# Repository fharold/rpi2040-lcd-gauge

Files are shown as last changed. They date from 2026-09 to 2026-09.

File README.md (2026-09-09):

# universal_gauges

Basic and versatile gauges based on the WAVESHARE RP2040-LCD-1.28 module.
A small HAT enhances it:

- 2 analog sensor inputs (divider stuffed to suit the sender, 5 V supply)
- 2 digital inputs (level shifted)
- 1 ambient light sensor
- 1 button
- 2 relay outputs

The firmware sources are in the repository root; the HAT itself is a KiCad
project in `pcb/`, described in [The HAT board](#the-hat-board).

The target is the **RP2040-LCD-1.28**. The touch variant is not supported: its
user button sits on GP16, which the HAT uses for its first digital input, so
the two would share one pin.

## Pinout

Signals added by the HAT:

| GPIO | Signal | Direction |
| ---- | --- | --- |
| GP16 | shifted_digital_in1 | input |
| GP17 | shifted_digital_in2 | input |
| GP18 | button_input | input, pull-up |
| GP19 | relay1_command_pin | output |
| GP20 | relay2_command_pin | output |
| GP26 | als_out | analog input, ADC0 |
| GP27 | sensor2_filtered | analog input, ADC1 |
| GP28 | sensor1_filtered | analog input, ADC2 |

The RP2040 ADC channel is not the GPIO number: GP26 is ADC0, GP27 is ADC1,
GP28 is ADC2, and GP29 (ADC3) is the module's own battery sense.

Pins used by the module itself (display, I2C, IMU, backlight, battery) are
defined in `lib/lcd/lcd.h`.

## The HAT board

The HAT is a KiCad 10 project, `pcb/rpi2040-lcd-gauge.kicad_pro`: a two-layer
board, 1.6 mm, 35 x 38.7 mm, whose lower edge is a semicircle following the
module. It sits
behind the RP2040-LCD-1.28 and connects to it through J2, a 2x10 1.27 mm
header. J1 is the header on the other side of the module; it is mechanical
only, none of its pads is connected.

The schematic is hierarchical, one sheet per function:

| Sheet | File | Contents |
| ----- | ---- | --- |
| psu | `PSU.kicad_sch` | input protection, 12 V -> 5 V buck |
| ain_1, ain_2 | `sensor_1.kicad_sch`, `sensor_2.kicad_sch` | analog input dividers |
| din_1, din_2 | `digital_in_1.kicad_sch`, `digital_in_2.kicad_sch` | level-shifted digital inputs |
| relay_1, relay_2 | `output_relay_1.kicad_sch`, `relay.kicad_sch` | low-side relay drivers |
| als | `als.kicad_sch` | ambient light sensor |
| switch | `switch.kicad_sch` | push button |

### Connectors

All field wiring is on JST XH connectors, 2.5 mm pitch.

| Ref | Type | Pin 1 | Pin 2 | Pin 3 | Pin 4 |
| --- | ---- | ----- | ----- | ----- | ----- |
| J5 | XH 4 | GND | digital_in1 | digital_in2 | +12 V in |
| J7 | XH 3 | sensor1 signal | GND | +5 V out | |
| J8 | XH 3 | sensor2 signal | GND | +5 V out | |
| J3 | XH 2 | +12 V | relay1 coil, low-side switched | | |
| J4 | XH 2 | +12 V | relay2 coil, low-side switched | | |

J2 carries GP16-GP22 to the module, +5 V to it, 3.3 V back from it, and GND.

### Power

The 12 V input passes through F1 (1 A), Q1 (P-channel MOSFET, reverse polarity
protection) and D2 (SMBJ36A TVS) onto the protected +12 V rail, which also
feeds the relay connectors. U1, an LMR16006 buck with L1 (22 uH) and the
R2/R3 feedback divider (54k9 / 10k), makes 5 V from that rail and supplies the
module through J2. The 3.3 V used by the ambient light sensor comes back from
the module's own regulator.

### Input and output stages

**Analog inputs.** Each is a divider to GND: R15 in series, the ADC pin, then
R16 to ground (R17/R18 on the second channel). **The two resistors are stuffed
to suit the sender the board is built for**, so a board and the firmware
variant flashed on it have to match.

*Pressure board, R15 = R16 = 100 k.* The sender has a voltage output and the
divider simply halves it: a 0.5-4.5 V sender spans 250-2250 mV at the pin.
Source impedance there is 50 k.

*Temperature board, R15 = 6 k, R16 = 10 k.* The sender is resistive and wired
between the connector's +5 V and its signal pin, so it becomes the top of the
divider and the pin reads

    V = 5 V x 10k / (R_sender + 16k)

which is 3.125 V with the sender shorted — comfortably under the 3.3 V full
scale — and 0 V with it open or its wire broken. Source impedance runs 4 to
7 k over the sender's range.

**Digital inputs.** Each is clamped by an SMAJ18A, divided 10 k / 100 k,
clamped again by a BZX84C12, and drives the gate of a BSS138 whose drain is
the GPIO, pulled up to 3.3 V through 10 k with 10 nF to GND. **The stage
inverts**: the GPIO reads low when the input is driven high, and idles high
when the input is open or grounded.

**Relay outputs.** GP19 and GP20 drive IRLML0060 MOSFETs through 1 k, with
100 k gate pulldowns, switching the low side of a coil fed from +12 V. There
is no flyback diode on the HAT: use a relay that has one built in, or fit one
across the coil.

**Button and light sensor.** SW1 pulls GP18 to GND, against the RP2040's
internal pull-up. U3, an SFH 5711 logarithmic light sensor, sinks its output
current into R11 (47 k) on GP26.

### Fabrication

`pcb/gerber/` holds the plot exported from KiCad 10.0.5, also zipped as
`pcb/gerber.zip`: two copper layers, mask, silkscreen, paste, and the PTH and
NPTH drill files. `pcb/rpi2040-lcd-gauge.csv` is the BOM.

## Source layout

| File | Contents |
| ---- | --- |
| `main.c` | bring-up order and the main loop, nothing else |
| `config.h` | every number you would tune: sensor spans, scales, backlight, sampling |
| `variant.h`, `variant.c` | the gauge variants, and the one this build selects |
| `board.h`, `board.c` | pin map, I2C scan, which of the two modules is running |
| `sensors.h`, `sensors.c` | ADC readings and their conversion to engineering units |
| `gauge.h`, `gauge.c` | frame buffer, gauge face and needle |
| `demo.h`, `demo.c` | the demo sweep, only compiled into a `USE_DEMO` build |
| `w.c`, `lib/` | widgets, drawing and display, from picoclock |

## Build variants

The firmware is built in three variants, selected at compile time by
`CURRENT_MODE`. One `cmake` + `make` builds all three:

| Variant | `CURRENT_MODE` | Gauge | Output |
| --- | --- | ----- | --- |
| engine oil temperature | `MODE_OIL_T` | 50-140 °C | `main_oil_t.uf2` |
| gearbox oil temperature | `MODE_GEARBOX_T` | 50-140 °C | `main_gearbox_t.uf2` |
| engine oil pressure | `MODE_OIL_P` | -0.5-6.5 bar | `main_oil_p.uf2` |

**The sensor is always wired to SENSOR1 (GP28), in every variant.** What the
variant changes is the input span applied to that reading, the quantity it
feeds, and the gauge face drawn behind the needle. It also has to match how
the board's input divider is stuffed, see
[Input and output stages](#input-and-output-stages). SENSOR2 is not used by any
variant; its pad is only configured as an analog input so it stays
high-impedance.

Each target is declared in `CMakeLists.txt` by the `universal_gauges_variant`
function. What separates one variant from another — input span, scale, reading
granularity and gauge face — is a `gauge_variant` structure. Adding a variant
means adding a `MODE_xxx` value in `variant.h`, one structure in `variant.c`
and one `universal_gauges_variant` call in `CMakeLists.txt`. Nothing else in
the firmware tests `CURRENT_MODE`.

### Calibration

All in `config.h`. Input spans, in millivolts, measured at the ADC pin:

| Define | Default | Meaning |
| --- | --- | --- |
| `TEMP_SENSOR_MV_MIN` / `_MAX` | 1470 / 2960 | ends of the temperature curve below |
| `PRESSURE_SENSOR_MV_MIN` / `_MAX` | 250 / 2250 | pressure sensor output range |
| `ALS_MV_MIN` / `_MAX` | 0 / 2700 | ambient light sensor output range |

The temperature sender is an NTC and is nowhere near linear, so it is
described by `TEMP_SENSOR_CURVE`, a table of measured (mV, °C) points ordered
by rising mV:

| mV at GP28 | °C | sender |
| --- | -- | --- |
| 1470 | 50 | 17.9 k |
| 1770 | 60 | 12.3 k |
| 2030 | 70 | 8.61 k |
| 2260 | 80 | 6.14 k |
| 2450 | 90 | 4.43 k |
| 2590 | 100 | 3.32 k |
| 2700 | 110 | 2.55 k |
| 2780 | 120 | 1.91 k |
| 2860 | 130 | 1.51 k |
| 2910 | 140 | 1.17 k |
| 2960 | 150 | 0.90 k |

Between two points the reading is interpolated, outside the table it is
clamped. `TEMP_SENSOR_MV_MIN` and `_MAX` have to stay equal to the first and
last mV of the table: they are what the percentage readout uses. Re-measuring
the sender means replacing the rows, nothing else. A variant whose
`gauge_variant` carries no curve — the pressure one — keeps the plain linear
span.

Display scales, in engineering units:

| Define | Default |
| --- | --- |
| `MIN_TEMP` / `MAX_TEMP` | 50 / 140 °C |
| `MIN_PRESS` / `MAX_PRESS` | -0.5 / 6.5 bar |

A reading below `_MIN` or above `_MAX` is clamped, not extrapolated. Change the
mV values to match a different sensor; change the unit values only if the gauge
face graduations change too. Note that the sender reaches 150 °C while the face
stops at 140: the needle parks on the last graduation above that.

The ADC is read every `ADC_PERIOD_MS` (100 ms), oversampled `ADC_SAMPLES` (8)
times per reading. The ambient light sensor drives the backlight between
`MIN_BRIGHTNESS` and `MAX_BRIGHTNESS`.

### Day and night

The same ambient light reading picks the gauge face: the `_dark` faces and the
orange needle below `THEME_NIGHT_BELOW` (20 %), the day faces and the red
needle above `THEME_DAY_ABOVE` (25 %).

| Define | Default | Meaning |
| --- | --- | --- |
| `THEME_NIGHT_BELOW` | 20 | % of the ALS span under which the night face is used |
| `THEME_DAY_ABOVE` | 25 | % over which the day face is used |
| `THEME_HOLD_MS` | 2000 | how long a reading has to disagree with the face on screen |

Between the two thresholds nothing changes, so a reading sitting on the edge
cannot flip the face back and forth; set them equal for a plain single
threshold. On top of that the new reading has to hold for `THEME_HOLD_MS`
before the face is swapped, so a bridge or a row of trees does not repaint the
screen. A demo build holds the light at `DEMO_LIGHT_PERCENT` (100 %) and so
always shows the day face; lower it below 20 to look at the night one.

## Building the image

The Pico SDK is required, and CMake has to be able to find it:

`export PICO_SDK_PATH=/path/to/pico-sdk`

Alternatively, `export PICO_SDK_FETCH_FROM_GIT=1` lets CMake clone it. Then:

`mkdir build;cd build;cmake ..;make`

This produces the three `.uf2` files in `build/`.

## Demo mode

A demo build sweeps the needle across the face, end to end and back, and
ignores the sensor. It is the quick way to check a gauge face, the needle
geometry and the end stops with nothing wired to SENSOR1. It is off by
default and has to be asked for when configuring:

`mkdir build-demo;cd build-demo;cmake -DUSE_DEMO=ON ..;make`

Its targets are named `main_<variant>_demo`, so a demo image never overwrites
a real one and `pilo oil_t` can never pick one up by mistake. `pilo` takes them
under that name, and says so before flashing:

`./tool/pilo oil_t_demo`

The sweep takes `DEMO_SWEEP_MS` (4 s) each way with a `DEMO_HOLD_MS` (500 ms)
pause at each end, and the backlight is held at `DEMO_LIGHT_PERCENT` (100 %)
so the needle stays visible whatever the ambient light. The three are in
`config.h`. The analog inputs are still read and printed on the serial link,
so a demo build also shows whether the ADC side is alive, and the first line
it prints says `demo build`.

## Flashing the image

Put the board in BOOTSEL — hold BOOT while plugging it in, or double-tap reset,
as the build links `pico_bootsel_via_double_reset` — then:

`./tool/pilo oil_t`     engine oil temperature
`./tool/pilo gearbox_t` gearbox oil temperature
`./tool/pilo oil_p`     engine oil pressure

`./tool/pilo` with no argument lists the variants, their `_demo` counterparts
and where each `.uf2` was found. It warns when the sources are newer than the binary, and takes an
explicit file too: `./tool/pilo build/main_oil_p.uf2`. See
`tool/tools.md` for the environment overrides.

The equivalent by hand:

`picotool load ./build/main_oil_t.uf2 -x`

`sudo` is needed on Linux but not on macOS. With several boards connected,
list them with `picotool info -a` and target one with
`--bus <bus> --address <addr>`.

## Releases

Firmware images are not versioned in git; they are attached to GitHub
releases. Pushing a `v*` tag builds the three variants on GitHub and publishes
them:

`git tag v1.0.0 && git push origin v1.0.0`

The workflow is `.github/workflows/release.yml`. It also runs on
`workflow_dispatch`, and every run uploads the `.uf2` files as build
artifacts, so a build can be checked without publishing anything.

To publish from this machine instead — same three variants, built locally and
uploaded with the GitHub CLI:

`./tool/pirel v1.0.0`

`pirel` refuses to run on a dirty working tree, and passes extra arguments
through to `gh release create` (`--prerelease`, `--draft`, `--notes ...`).
Prefer the tag-triggered workflow for anything official: it does not depend on
this machine.

To flash an image downloaded from a release, give `pilo` its path:

`./tool/pilo ~/Downloads/main_oil_p.uf2`

## Tools

Scripts for flashing, releasing, serial shell, LCD screenshots, and converting
images and fonts into header files live in `tool/`, documented in
`tool/tools.md`. The images and fonts themselves are in `img/`, and the KiCad
project for the HAT is in `pcb/`.

## Known issues

- battery display has to be adjusted depending on battery type
- a broken sender wire reads a clean 0 mV, R16 pulling the pin down, and on a
  temperature board a shorted sender reads 3125 mV. Both fall outside the
  calibration, so both are recognisable, but the firmware only clamps them to
  the ends of the scale instead of showing a fault
- the analog inputs are named `SENSOR*_FILTERED` but there is no filter: no
  capacitor sits across the divider. On a pressure board it also presents 50 k
  to the ADC pin, more than the RP2040 would like; the 6 k / 10 k of a
  temperature board is fine
- nothing on a board says which sender it is stuffed for, and nothing stops
  `pilo` from flashing the wrong variant onto it
- the layout is one annotation behind the schematic. The catch diode is D7 in
  the schematic and still D4 on the board, which therefore carries two D4s,
  and SW1 is `SW` there. The gerbers were plotted before the last schematic
  edits, so re-annotate and re-plot before ordering
- the schematic and the BOM give R15 to R18 as 100 k, the pressure stuffing;
  the 6 k / 10 k of a temperature board is only written down in `config.h`

## Credits

Based on [dawigit/picoclock](https://github.com/dawigit/picoclock) — the
display, widget, drawing and font code, and the tooling in `tool/`, come from
that project.

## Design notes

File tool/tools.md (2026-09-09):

## pilo

### usage: pilo VARIANT
#### example: pilo oil_p
#### flashes a build variant onto an RP2040 in BOOTSEL mode

- `pilo` without argument lists the variants, their demo counterparts, and where each `.uf2` was found
- variants: `oil_t` (engine oil temp), `gearbox_t` (gearbox oil temp), `oil_p` (engine oil pressure)
- add `_demo` for a demo image, the one built with `cmake -DUSE_DEMO=ON`, whose
  needle sweeps the face on its own: `pilo oil_p_demo`. It says so before flashing
- looks in `build/` then `build-demo/`; warns if any source, library or image
  header is newer than the `.uf2`
- an explicit file also works: `pilo build/main_oil_p.uf2`
- `sudo` is used on Linux only; override with `PILO_SUDO=0` / `PILO_SUDO=1`
- with several boards in BOOTSEL, pick one: `PILO_BUS=1 PILO_ADDRESS=5 pilo oil_p`
  (find the values with `picotool info -a`)

To get the board into BOOTSEL: hold BOOT while plugging it in, or double-tap
reset - the build links `pico_bootsel_via_double_reset`.

## pirel

### usage: pirel TAG [gh release create args...]
#### example: pirel v1.0.0
#### builds the three variants and publishes them as a GitHub release

- requires the GitHub CLI (`gh`) and `PICO_SDK_PATH`
- refuses to run on a dirty working tree
- extra arguments go to `gh release create`: `pirel v1.0.0-rc1 --prerelease`
- for official releases prefer pushing a `v*` tag and letting
  `.github/workflows/release.yml` build it, so the build does not depend on
  one machine

## pigsh

### usage: pigsh ttyACMn
#### example: pigsh 0
#### connect to your device, send commands, make screenshots

## snaps
### usage: snaps ACMNUMBER FILENAME
### example: snaps 0 mysnapshot
- starts a snapshot reading data from /dev/ttyACM0 [ACMNUMBER]
- the 'bmp' image will be converted (and flipped) to 'png'
- your output file name will be: 'mysnapshot.png' according to the above example
- if it hangs reset your device and repeat the process

snaps will call mksnap ACMNUMBER FILENAME
sleeps 2 seconds
then sends " " then "SNAPSHOT" to /dev/ttyACM[ACMNUMBER]
mksnap will open the 'png' with eog image viewer (if installed)

## snaps via ssh?
### example:
### ssh user@host 'cd universal_gauges/img; ../tool/snaps 1 mysnap'
### universal_gauges has to be in your home '/home/user/universal_gauges'
- connects to your host (like jim@raspi4 )
- changes to your 'universal_gauges/img' folder in your home (so images saved are there)
- calls 'snaps' script from 'tools' folder
- connection finished - ssh stuff done
##

### local image view: [you work from a linux system, ssh connected to a pi]
### ssh user@host 'cd universal_gauges/img; ../tool/snaps 1 mysnap'; eog mysnap.png
- assumptions:
- 'sshfs user@host:/home/user/universal_gauges' ./universal_gauges
- cd ~/universal_gauges/img
- my pi4 is headless, so no X installed.

### from your local terminal:
- ssh user@host 'cd universal_gauges/img; ../tool/snaps 1 mysnap'; eog mysnap.png

## obsolete [use snaps]
### snapshot

i left the old code if you want to play

### usage: snapshot CUTFILE
#### example: snapshot s_cn
#### converts data from device to image

### connect the RP2040-LCD-1.28 via USB to your Pi

#### in a terminal:

1. pigsh 0
2. press return once (the first input is ignored)
3. type 'SNAPSHOT' and press enter
4. in a 2nd terminal: 'cat /dev/ttyACM0 > snapshotcut'
    - the pointer should be 'frozen' now on the clock, data is transmitted
    - when the pointer starts moving again press 'control+c'
5. snapshot snapshotcut
6. hopefully creates snapshotcut.bmp
## obsolete

## img2data

### usage: img2data IMAGEFILE SIZE*SIZE
#### example: img2data us16.png 16*16
#### generates file 'us16.h' with rgb565 data

#### you can add it to your .bashrc or whatever you use

function img2data()
{
oname=$(echo "$1" | cut -f 1 -d '.')
name=$(echo "$1" | cut -f 1 -d '.')rgb565
echo "name: $name"
convert $1 -rotate 180 -flop -alpha off -define bmp:subtype=RGB565 $name.bmp
#conversion: swap bytes (hi/lo)
dd conv=swab bs=138 skip=1 if=$name.bmp of=$oname.raw
touch $oname.h
echo "const unsigned char $oname[$2*2] = {" > $oname.h
hexdump -v -e '"0x" 1/1 "%02X" ","' $oname.raw >> $oname.h
rm $oname.raw
rm $name.bmp
echo "};" >> $oname.h
}

## earth / eye texture creation

- create earth.png with 256*256 size

- (sc)roll image to center:
`convert earth.png -roll +128+128 e8.png`

- this process is reversible:
`convert e8.png -roll +128+128 earth256.png`
 creates the 'regular' earth image

- now we need the image data as header file:
`img2data e8.png 256*256`

e8.h is ready to be included.

## mkfontimagexy

### usage: mkfontimagexy FONT X Y POINTSIZE
#### example: mkfontimagexy nf.ttc 31 40 27;
#### generates file 'nf.tcc.png' (2color)

#### POINTSIZE is responsible for X/Y of fonts so you have 'play' with the values a bit

A complete conversion process would be:
- install fonts
`cp /usr/share/fonts/opentype/noto/NotoSansCJK-Thin.ttc ./nf.ttc`
`mkfontimagexy nf.ttc 31 40 27`
`eog nf.ttc.png`

This generates 'nf.ttc.h' (aka Font40.h) and Font30.h is made alike.
Those fonts contain Latin, Cyrillic and a bunch of 'Chinese' characters – to write the weekdays.
A bit of show - generally it's NOT a good idea mixing fonts of different dimensions (rect vs. square)
or better: square-rect == waste-o-space

function mkfontimagexy()
{
convert -size $2x$((235*$3)) xc:black -font "$1" -pointsize $4 -fill white -draw "@b.txt" -threshold 0% -depth 1 -flip $1.png
convert $1.png -depth 1 $1.bmp
dd bs=150 skip=1 if=$1.bmp of=$1.raw
xxd -i $1.raw $1.h
rm $1.bmp
rm $1.raw
sed -i -r 's/\w+\[\]/Font'$3'_table\[\]/g' $1.h
sed -i -r 's/\w+_len/Font'$3'_len/g' $1.h
echo -e "\nsFONT Font"$3" = {\n  Font"$3"_table,\n  "$2", /* Width */\n  "$3", /* Height */\n};\n" >> $1.h
}

## New font functions

### Generate the textfile containing the draw information for 'imagemagick'
### eg: 'mkfontmt asian.txt'
### The glyphs string contains the sorted (utf8 to 4byte) glyphs (characters)
### (the sorting 1,3,2,.... in 'chinese' is correct because in 4byte '三' comes before '二')
### In the code search for 'lcd_makeutf8table(' in 'main('
### Where every 'word' is added to one big string.
### This string is striped of dupes and finally sorted to build an index table.
### Check the debug output for the complete, sorted string. 
### IF you introduce new glyphs/characters (a word with a character that has not yet occured)
### you also have to generate new fonts containing these glyphs/characters

function mkfontmt()
{
glyphs="一三二五六四土日星曜月期木水火金금목수요월일토화"
for (( i=0; i<${#glyphs}; i++ )); do
  echo "text 0,$((($i+1)*$1)) '${glyphs:$i:1}'" >> $2
done
}

function mkfontm32()
{
NUMCHARS=24
echo $NUMCHARS
echo "NUMCHARS: $NUMCHARS"
convert -size $3x$(($NUMCHARS*$4)) xc:black -fill white -stroke '#3333aa' -strokewidth 1 -font "$1" -density 72 -pointsize $2 -draw "@multi_asian.txt" -roll +1-8 -crop +0+0 -crop +0-0 -flip -colorspace RGB png24:$5.png
convert $5.png -define bmp:subtype=RGB565 $5.bmp
dd conv=swab bs=138 skip=1 if=$5.bmp of=$5.raw
xxd -i $5.raw $5.h
rm $5.bmp
rm $5.raw
sed -i -r 's/unsigned char/const char/' $5.h
sed -i -r 's/\w+\[\]/fa'$4'_table\[\]/g' $5.h
sed -i -r 's/\w+_len/fa'$4'_len/g' $5.h
echo -e "\nfont_t fa"$4" = {\n  fa"$4"_table,\n  "$3", /* Width */\n  "$4", /* Height */\n "$NUMCHARS", /* number of chars */\n  "$(((NUMCHARS-1)*$3))" /* modulo */\n};\n" >> $5.h
}

function mkfontm()
{
NUMCHARS=24
echo "NUMCHARS: $NUMCHARS"
convert -size $3x$(($NUMCHARS*$4)) xc:black -fill white -stroke '#3333aa' -strokewidth 1 -font "$1" -density 72 -pointsize $2 -draw "@multi_a40.txt" -roll +2-8 -crop +0+0 -crop +0-0 -flip -colorspace RGB png24:$5.png
convert $5.png -define bmp:subtype=RGB565 $5.bmp
dd conv=swab bs=138 skip=1 if=$5.bmp of=$5.raw
xxd -i $5.raw $5.h
rm $5.bmp
rm $5.raw
sed -i -r 's/unsigned char/const char/' $5.h
sed -i -r 's/\w+\[\]/fa'$4'_table\[\]/g' $5.h
sed -i -r 's/\w+_len/fa'$4'_len/g' $5.h
echo -e "\nfont_t fa"$4" = {\n  fa"$4"_table,\n  "$3", /* Width */\n  "$4", /* Height */\n "$NUMCHARS", /* number of chars */\n  "$(((NUMCHARS-1)*$3))" /* modulo */\n};\n" >> $5.h
}

function mkfont_asian()
{
mkfontm32 ./NotoSansCJK-Bold.ttc 20 24 32 fa32; eog fa32.png;feh fa32.png
mkfontm ./NotoSansCJK-Bold.ttc 25 30 40 fa40; eog fa40.png;feh fa40.png
}

function mkfont_kyrillic()
{
mkfontkyr32 ./OpenSans-Regular.ttf 28 22 32 fkyr32;eog fkyr32.png;feh fkyr32.png
mkfontkyr ./OpenSans-ExtraBold.ttf 25 24 40 fkyr40; eog fkyr40.png;feh fkyr40.png
}

function mkfontkyr()
{
NUMCHARS=18
echo "NUMCHARS: $NUMCHARS"
convert -size $3x$(($NUMCHARS*$4+8)) xc:black -fill white -kerning 1 -density 72 -font "$1" -pointsize $2 -draw "@multi_kyr40.txt" -roll +2-6 -crop +0+0 -crop +0-0 -flip -colorspace RGB png24:$5.png
convert $5.png -define bmp:subtype=RGB565 $5.bmp
dd conv=swab bs=138 skip=1 if=$5.bmp of=$5.raw
xxd -i $5.raw $5.h
rm $5.bmp
rm $5.raw
sed -i -r 's/unsigned char/const char/' $5.h
sed -i -r 's/\w+\[\]/fkyr'$4'_table\[\]/g' $5.h
sed -i -r 's/\w+_len/fkyr'$4'_len/g' $5.h
echo -e "\nfont_t fkyr"$4" = {\n  fkyr"$4"_table,\n  "$3", /* Width */\n  "$4", /* Height */\n "$NUMCHARS", /* number of chars */\n  "$(((NUMCHARS-1)*$3))" /* modulo */\n};\n" >> $5.h
}

function mkfontkyr32()
{
NUMCHARS=$(stat --printf="%s" multi_kyr.txt)
echo $NUMCHARS
NUMCHARS=18
W=$4
echo "NUMCHARS: $NUMCHARS"
convert -size $3x$(($NUMCHARS*$4+4)) xc:black -fill white -kerning 1 -density 72 -font "$1" -pointsize $2 -draw "@multi_kyr.txt" -roll +1-4 -crop +0+0 -crop +0-0 -flip -colorspace RGB png24:$5.png
convert $5.png -define bmp:subtype=RGB565 $5.bmp   
dd conv=swab bs=138 skip=1 if=$5.bmp of=$5.raw
xxd -i $5.raw $5.h
rm $5.bmp
rm $5.raw
sed -i -r 's/unsigned char/const char/' $5.h
sed -i -r 's/\w+\[\]/fkyr'$W'_table\[\]/g' $5.h
sed -i -r 's/\w+_len/fkyr'$W'_len/g' $5.h
echo -e "\nfont_t fkyr"$W" = {\n  fkyr"$W"_table,\n  "$3", /* Width */\n  "$W", /* Height */\n "$NUMCHARS", /* number of chars */\n  "$(((NUMCHARS-1)*$3))" /* modulo */\n};\n" >> $5.h
}

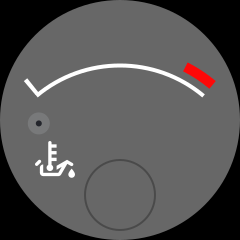
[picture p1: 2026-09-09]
img/bg_gauge_oil_t.png

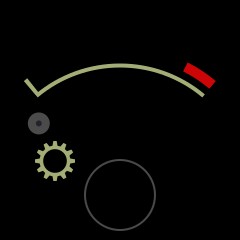
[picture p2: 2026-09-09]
img/bg_gearbox_temp_dark.png

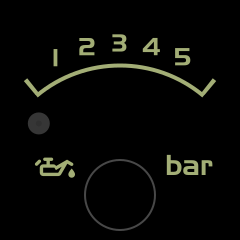
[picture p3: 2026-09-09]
img/bg_gauge_oil_p_dark.png

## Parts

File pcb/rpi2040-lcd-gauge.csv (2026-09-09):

Reference | Qty | Value | DNP | Exclude from BOM | Exclude from Board | Exclude from Simulation | Exclude from Position Files | Footprint | Datasheet
C1 | 1 | 4u7/100V |  |  |  |  | ${EXCLUDE_FROM_POS_FILES} | Capacitor_SMD:C_1206_3216Metric_Pad1.33x1.80mm_HandSolder
C2,C3 | 2 | 10nF |  |  |  |  | ${EXCLUDE_FROM_POS_FILES} | Resistor_SMD:R_0805_2012Metric_Pad1.20x1.40mm_HandSolder
C4,C5 | 2 | 100nF |  |  |  |  | ${EXCLUDE_FROM_POS_FILES} | Resistor_SMD:R_0805_2012Metric_Pad1.20x1.40mm_HandSolder
C6 | 1 | 100n/100V |  |  |  |  | ${EXCLUDE_FROM_POS_FILES} | Resistor_SMD:R_0805_2012Metric_Pad1.20x1.40mm_HandSolder
C7 | 1 | 100n |  |  |  |  | ${EXCLUDE_FROM_POS_FILES} | Resistor_SMD:R_0805_2012Metric_Pad1.20x1.40mm_HandSolder
C8 | 1 | 22u/16V |  |  |  |  | ${EXCLUDE_FROM_POS_FILES} | Capacitor_SMD:C_1206_3216Metric_Pad1.33x1.80mm_HandSolder
C9 | 1 | 100n/16V |  |  |  |  | ${EXCLUDE_FROM_POS_FILES} | Capacitor_SMD:C_1206_3216Metric_Pad1.33x1.80mm_HandSolder
D1 | 1 | BZX84C15 |  |  |  |  | ${EXCLUDE_FROM_POS_FILES} | Package_TO_SOT_SMD:SOT-23
D2 | 1 | SMBJ36A |  |  |  |  | ${EXCLUDE_FROM_POS_FILES} | Diode_SMD:D_SMB
D3,D5 | 2 | SMAJ18A |  |  |  |  | ${EXCLUDE_FROM_POS_FILES} | Diode_SMD:D_SMA
D4,D6 | 2 | BZX84C12 |  |  |  |  | ${EXCLUDE_FROM_POS_FILES} | Package_TO_SOT_SMD:SOT-23
D7 | 1 | B1100 |  |  |  |  | ${EXCLUDE_FROM_POS_FILES} | Diode_SMD:D_SMA
F1 | 1 | 1A |  |  |  |  | ${EXCLUDE_FROM_POS_FILES} | Fuse:Fuse_1206_3216Metric
FB1 | 1 | 600R/2A |  |  |  |  | ${EXCLUDE_FROM_POS_FILES} | Inductor_SMD:L_1206_3216Metric_Pad1.22x1.90mm_HandSolder
J1,J2 | 2 | Screen header |  |  |  |  | ${EXCLUDE_FROM_POS_FILES} | Connector_PinHeader_1.27mm:PinHeader_2x10_P1.27mm_Vertical
J3 | 1 | relay1_coil |  |  |  |  | ${EXCLUDE_FROM_POS_FILES} | Connector_JST:JST_XH_B2B-XH-A_1x02_P2.50mm_Vertical
J4 | 1 | relay2_coil |  |  |  |  | ${EXCLUDE_FROM_POS_FILES} | Connector_JST:JST_XH_B2B-XH-A_1x02_P2.50mm_Vertical
J5 | 1 | supply |  |  |  |  | ${EXCLUDE_FROM_POS_FILES} | Connector_JST:JST_XH_B4B-XH-A_1x04_P2.50mm_Vertical
J7 | 1 | sens1 |  |  |  |  | ${EXCLUDE_FROM_POS_FILES} | Connector_JST:JST_XH_B3B-XH-A_1x03_P2.50mm_Vertical
J8 | 1 | sens2 |  |  |  |  | ${EXCLUDE_FROM_POS_FILES} | Connector_JST:JST_XH_B3B-XH-A_1x03_P2.50mm_Vertical
L1 | 1 | 22uH/1A |  |  |  |  | ${EXCLUDE_FROM_POS_FILES} | Inductor_SMD:L_Bourns_SRN6045TA
Q1 | 1 | P-MOS 100V |  |  |  |  | ${EXCLUDE_FROM_POS_FILES} | Package_TO_SOT_SMD:SOT-223-3_TabPin2
Q2,Q3 | 2 | BSS138 |  |  |  |  | ${EXCLUDE_FROM_POS_FILES} | Package_TO_SOT_SMD:SOT-23
Q4,Q5 | 2 | IRLML0060 |  |  |  |  | ${EXCLUDE_FROM_POS_FILES} | Package_TO_SOT_SMD:SOT-23 | https://www.infineon.com/dgdl/irlml0030pbf.pdf?fileId=5546d462533600a401535664773825df
R1,R5,R7,R9,R13,R15,R16,R17,R18 | 9 | 100k |  |  |  |  | ${EXCLUDE_FROM_POS_FILES} | Resistor_SMD:R_0805_2012Metric_Pad1.20x1.40mm_HandSolder
R2 | 1 | 54k9 |  |  |  |  | ${EXCLUDE_FROM_POS_FILES} | Resistor_SMD:R_0805_2012Metric_Pad1.20x1.40mm_HandSolder
R3,R4,R10,R12,R14 | 5 | 10k |  |  |  |  | ${EXCLUDE_FROM_POS_FILES} | Resistor_SMD:R_0805_2012Metric_Pad1.20x1.40mm_HandSolder
R6,R8 | 2 | 1k |  |  |  |  | ${EXCLUDE_FROM_POS_FILES} | Resistor_SMD:R_0805_2012Metric_Pad1.20x1.40mm_HandSolder
R11 | 1 | 47k |  |  |  |  | ${EXCLUDE_FROM_POS_FILES} | Resistor_SMD:R_0805_2012Metric_Pad1.20x1.40mm_HandSolder
SW1 | 1 | SW_Push |  |  |  |  | ${EXCLUDE_FROM_POS_FILES} | Button_Switch_SMD:SW_SPST_SKQG_WithoutStem
U1 | 1 | LMR16006XDDCT |  |  |  |  | ${EXCLUDE_FROM_POS_FILES} | Package_TO_SOT_SMD:SOT-23-6
U3 | 1 | SFH 5711 |  |  |  |  | ${EXCLUDE_FROM_POS_FILES} | Sensor_light:SFH 5711 | https://look.ams-osram.com/m/418ff004812c8684/original/SFH-5711.pdf

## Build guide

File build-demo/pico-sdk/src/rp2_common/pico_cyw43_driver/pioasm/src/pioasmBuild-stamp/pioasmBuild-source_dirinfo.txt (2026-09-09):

# This is a generated file and its contents are an internal implementation detail.
# The download step will be re-executed if anything in this file changes.
# No other meaning or use of this file is supported.

method=source_dir
command=
source_dir=/Users/hfritsch/sdk/pico-sdk/tools/pioasm
work_dir=

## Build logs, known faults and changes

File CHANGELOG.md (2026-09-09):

### Changelog:

#### universal_gauges (fork)
- main.c split into modules: config.h (calibration), variant.c (the gauge
  variants, as a gauge_variant structure instead of scattered #if), board.c
  (pins and board detection), sensors.c (ADC), gauge.c (face and needle).
  main.c is now the bring-up order and the main loop
- the needle is clamped to the two ends of the gauge face instead of to zero,
  so the -0.5 to 0 bar part of the pressure scale is finally reachable
- the input divider is stuffed per sender: 100k/100k on a pressure board, which
  halves a voltage output, and 6k/10k on a temperature board, where the
  resistive sender is the top of the divider. A board and the variant flashed
  on it have to match
- temperature conversion follows a measured NTC curve (TEMP_SENSOR_CURVE, 11
  points from 50 to 150 C) instead of a straight line, which read up to 35 C
  too high in the middle of the range. Variants without a curve stay linear
- the day / night face now follows the ambient light: night under 20 %, day
  over 25 %, with a 2 s hold before either swap. NIGHT_THEME and the _dark
  faces were dead code until now
- support for the RP2040-TOUCH-LCD-1.28 dropped, with the CST816S driver: its
  button is on GP16, which the HAT uses as digital input 1. The board is now
  the RP2040-LCD-1.28, the I2C scan is only a boot diagnostic
- 'pilo' takes the demo targets as <variant>_demo, looks in build-demo/ as well
  as build/, and its stale-build check now covers every module, not just main.c
- demo mode, off by default, built with cmake -DUSE_DEMO=ON: the needle sweeps
  the face instead of following the sensor, targets named main_<variant>_demo
- 3 build variants (engine oil temp / gearbox oil temp / engine oil pressure),
  selected at compile time by CURRENT_MODE, one CMake target each
- sensor reading on SENSOR1 (ADC2) with oversampling, mV conversion and
  per-sensor calibration spans; ambient light sensor drives the backlight
- 'pilo' rewritten: takes a variant name, locates the .uf2, warns on stale
  builds, sudo on Linux only
- firmware images are no longer in git: attached to GitHub releases, built by
  .github/workflows/release.yml on a v* tag, or locally with 'pirel'

#### upstream (dawigit/picoclock)
- all tools/scripts moved to folder 'tool'
- img2data.md -> tool/tools.md
- spi transfer (at full speed) via dma -> 20fps
- raspberry texture added
- some seamless textures added (good with rotozoom)
- texture mapping (using hardware_interp)
  based on: [https://github.com/raspberrypi/pico-examples/tree/master/pio/st7789_lcd]
  (quadruple draw, mirroring) (rotate / rotozoom)
- gyroscope error correction
- 'main.uf2' for  RP2040-TOUCH-LCD-1.28 /  RP2040-LCD-1.28
- 'scandir' command added [0-3] (hardware) rotate display by 90°
- 'editpos' command added [0-8]
- load/save flash fixed. [restore save ram from flash now works]
- added new icons
- added config (next to center, opposite dotw)
- added more textures
- removed pointerdemo
- added textured pointers
- added alpha pointers
- added rotating background (themes 0,1)
- added rotozoom (from hagl [https://github.com/tuupola/hagl]) (cannon travel!)
- added "pico_bootsel_via_double_reset" in CMakeLists.txt
- more vars (values) now resist in 'noinit' ram
- battery display will flicker a lot at start (or when bat is lo) as it finds new min/max values
- when sleeping and a new lo-bat minimum was found, it saves (new minimum value)
- changed shell commands
- added flash ram
- added save: press the button for >3 sec when in center position (cursor/flag) to save save ram to flash ram
- gyrocross improved, shows ghosted old position
- battery display improved
- bending second pointer fixed at the star
- lcd_rect -> lcd_frame (and other changes in lcd)
- changed button system (internal)
- added battery types
- changed shell commands, see below
- snapshots with 'snaps' script: `snaps 0 mysnapfilename` [/dev/ttyACM0] (minicom must be stopped before)
- added shell: file 'pigsh' contains a simple bash script sending your input to /dev/ttyACMx (minicom has to be started before)
- 'pigsh 0' to connect to  /dev/ttyACM0
- 'pigsh 1' to connect to  /dev/ttyACM1

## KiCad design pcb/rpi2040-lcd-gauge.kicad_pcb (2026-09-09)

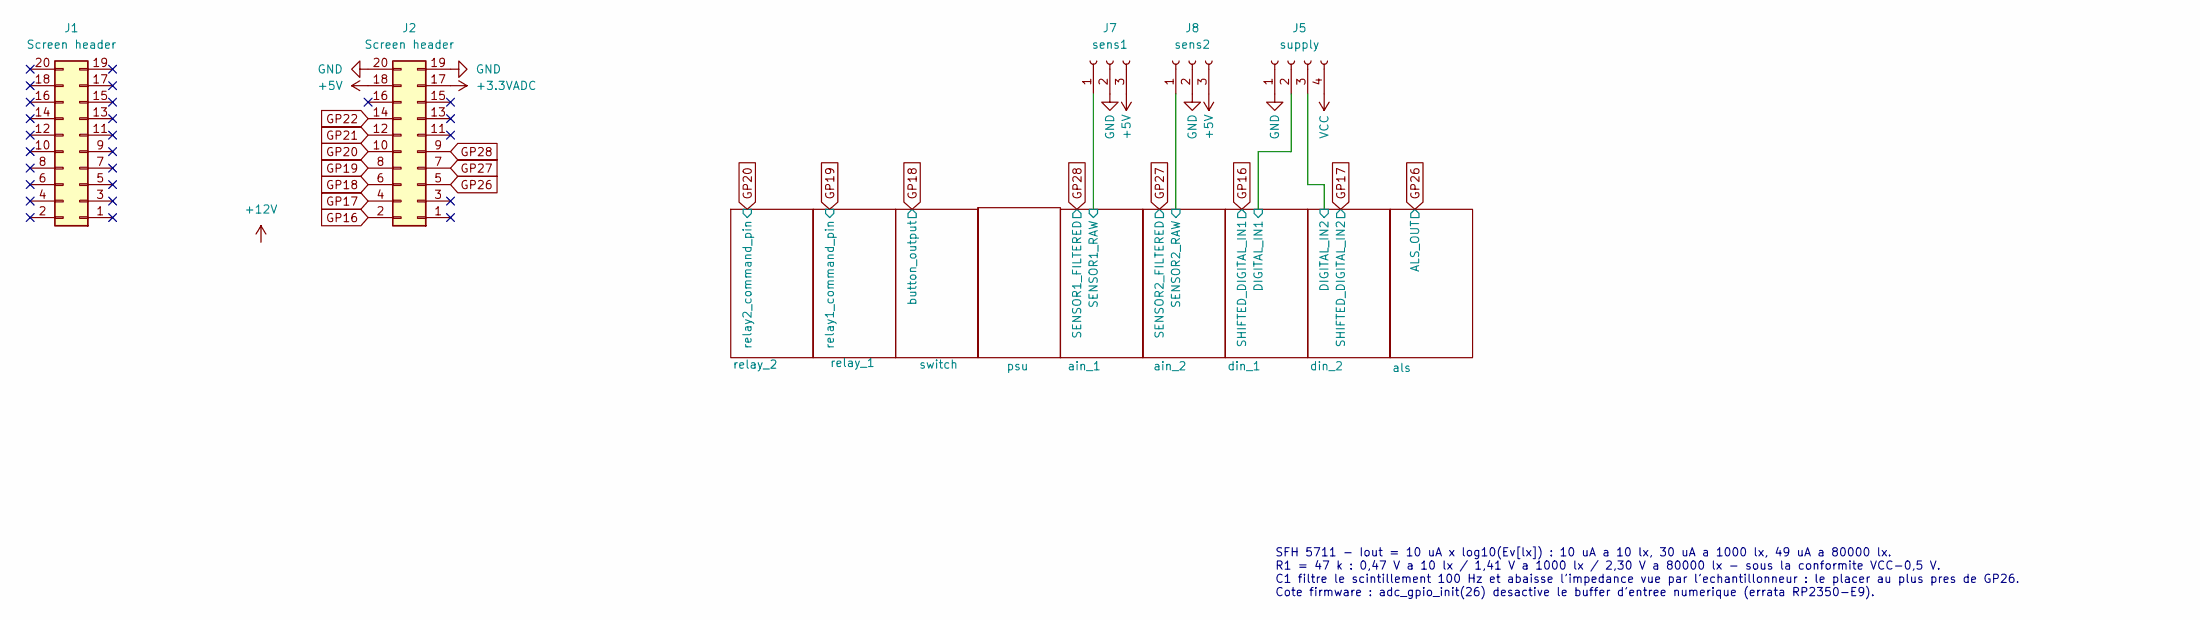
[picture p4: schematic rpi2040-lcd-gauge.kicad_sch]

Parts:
J1, J2: Screen header; PinHeader_2x10_P1.27mm_Vertical
J5: supply; JST_XH_B4B-XH-A_1x04_P2.50mm_Vertical
J7: sens1; JST_XH_B3B-XH-A_1x03_P2.50mm_Vertical
J8: sens2; JST_XH_B3B-XH-A_1x03_P2.50mm_Vertical

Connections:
+3.3VADC: J2.17; also elsewhere on the board
+5V: J2.18, J7.3, J8.3; also elsewhere on the board
/ain_1/SENSOR1_RAW: J7.1; also elsewhere on the board
/ain_2/SENSOR2_RAW: J8.1; also elsewhere on the board
/din_1/DIGITAL_IN1: J5.2; also elsewhere on the board
/din_2/DIGITAL_IN2: J5.3; also elsewhere on the board
GND: J2.19, J2.20, J5.1, J7.2, J8.2; also elsewhere on the board
GP16: J2.2; also elsewhere on the board
GP17: J2.4; also elsewhere on the board
GP18: J2.6; also elsewhere on the board
GP19: J2.8; also elsewhere on the board
GP20: J2.10; also elsewhere on the board
GP21: J2.12
GP22: J2.14
GP26: J2.5; also elsewhere on the board
GP27: J2.7; also elsewhere on the board
GP28: J2.9; also elsewhere on the board
VCC: J5.4; also elsewhere on the board

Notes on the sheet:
SFH 5711 - Iout = 10 uA x log10(Ev[lx]) : 10 uA a 10 lx, 30 uA a 1000 lx, 49 uA a 80000 lx. R1 = 47 k : 0,47 V a 10 lx / 1,41 V a 1000 lx / 2,30 V a 80000 lx - sous la conformite VCC-0,5 V. C1 filtre le scintillement 100 Hz et abaisse l'impedance vue par l'echantillonneur : le placer au plus pres d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

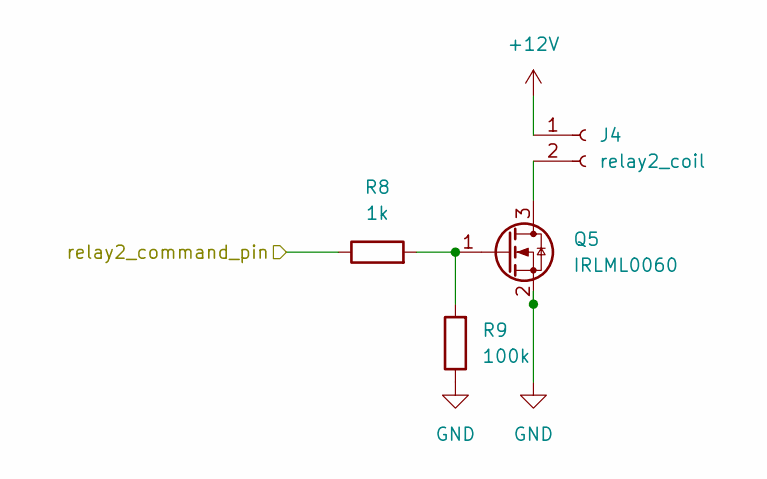
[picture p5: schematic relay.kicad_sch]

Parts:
J4: relay2_coil; JST_XH_B2B-XH-A_1x02_P2.50mm_Vertical
Q5: IRLML0060; SOT-23
R8: 1k; R_0805_2012Metric_Pad1.20x1.40mm_HandSolder
R9: 100k; R_0805_2012Metric_Pad1.20x1.40mm_HandSolder

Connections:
+12V: J4.1; also elsewhere on the board
GND: Q5.2 (S), R9.1; also elsewhere on the board
GP20: R8.1; also elsewhere on the board
unnamed: J4.2, Q5.3 (D)
unnamed: Q5.1 (G), R8.2, R9.2

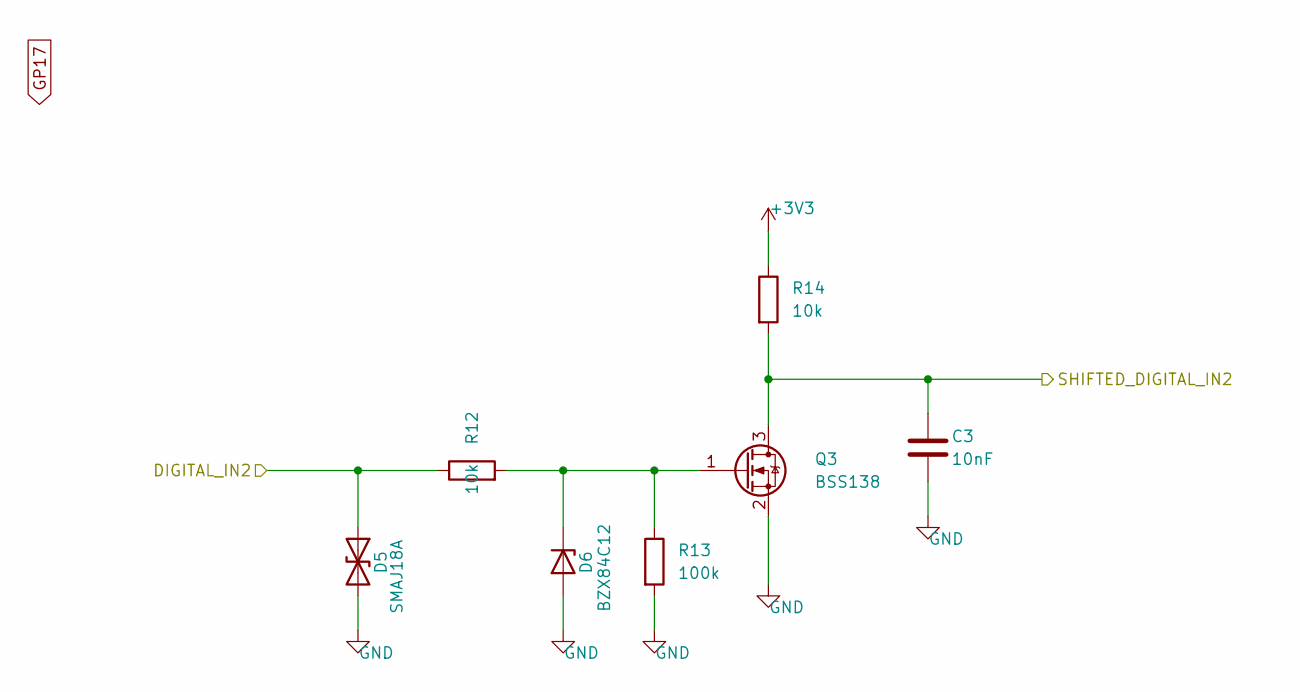
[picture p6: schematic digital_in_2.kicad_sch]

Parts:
C3: 10nF; R_0805_2012Metric_Pad1.20x1.40mm_HandSolder
D5: SMAJ18A; D_SMA
D6: BZX84C12; SOT-23
Q3: BSS138; SOT-23
R12, R14: 10k; R_0805_2012Metric_Pad1.20x1.40mm_HandSolder
R13: 100k; R_0805_2012Metric_Pad1.20x1.40mm_HandSolder

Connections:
+3V3: R14.1; also elsewhere on the board
/din_2/DIGITAL_IN2: D5.1 (A1), R12.1; also elsewhere on the board
GND: C3.2, D5.2 (A2), D6.2 (A), Q3.2 (S), R13.2; also elsewhere on the board
GP17: C3.1, Q3.3 (D), R14.2; also elsewhere on the board
unnamed: D6.1 (K), Q3.1 (G), R12.2, R13.1

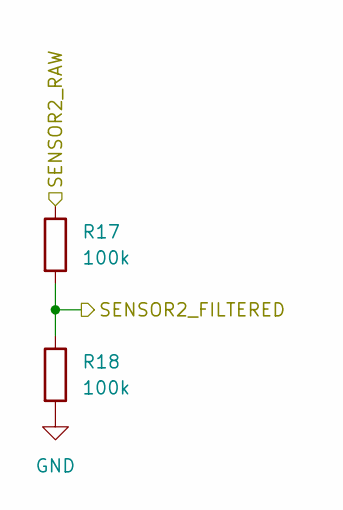
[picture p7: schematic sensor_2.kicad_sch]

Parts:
R17, R18: 100k; R_0805_2012Metric_Pad1.20x1.40mm_HandSolder

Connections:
/ain_2/SENSOR2_RAW: R17.1; also elsewhere on the board
GND: R18.2; also elsewhere on the board
GP27: R17.2, R18.1; also elsewhere on the board

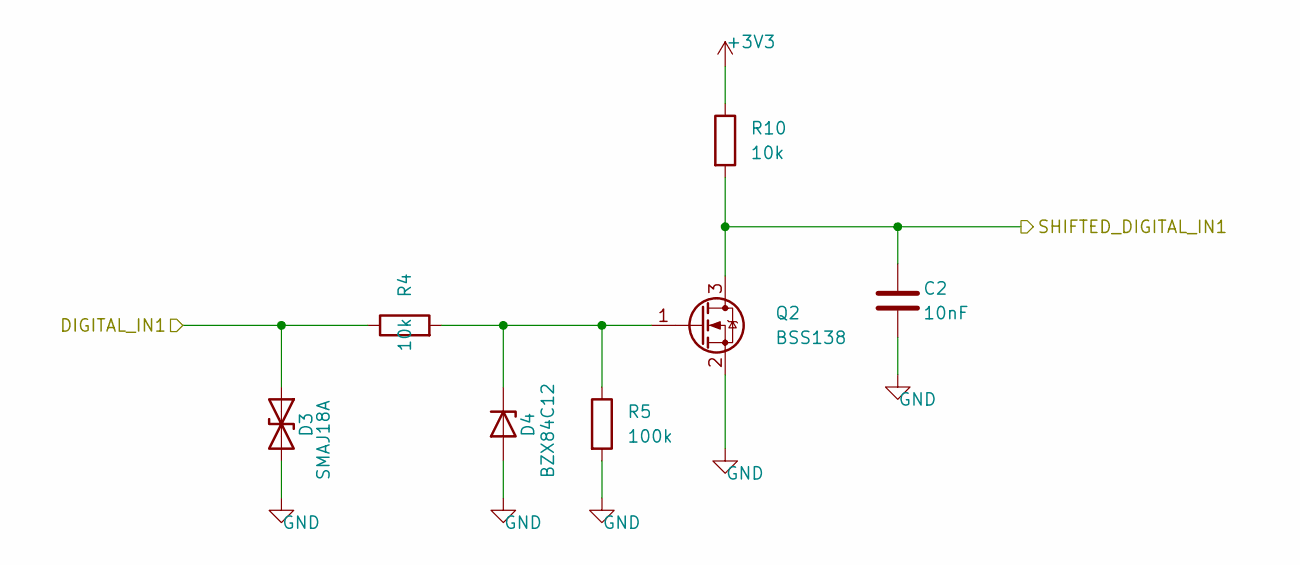
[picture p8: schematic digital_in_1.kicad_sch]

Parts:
C2: 10nF; R_0805_2012Metric_Pad1.20x1.40mm_HandSolder
D3: SMAJ18A; D_SMA
D4: BZX84C12; SOT-23
Q2: BSS138; SOT-23
R4, R10: 10k; R_0805_2012Metric_Pad1.20x1.40mm_HandSolder
R5: 100k; R_0805_2012Metric_Pad1.20x1.40mm_HandSolder

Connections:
+3V3: R10.1; also elsewhere on the board
/din_1/DIGITAL_IN1: D3.1 (A1), R4.1; also elsewhere on the board
GND: C2.2, D3.2 (A2), D4.2 (A), Q2.2 (S), R5.2; also elsewhere on the board
GP16: C2.1, Q2.3 (D), R10.2; also elsewhere on the board
unnamed: D4.1 (K), Q2.1 (G), R4.2, R5.1

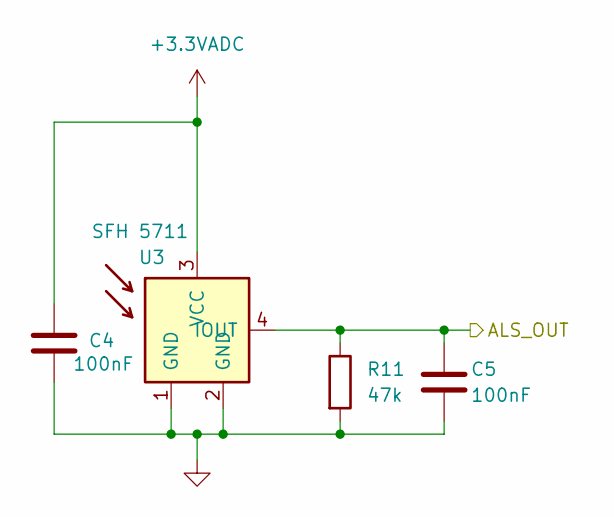
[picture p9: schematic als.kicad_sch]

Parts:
C4, C5: 100nF; R_0805_2012Metric_Pad1.20x1.40mm_HandSolder
R11: 47k; R_0805_2012Metric_Pad1.20x1.40mm_HandSolder
U3: SFH 5711

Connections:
+3.3VADC: C4.1, U3.3 (VCC); also elsewhere on the board
GND: C4.2, C5.2, R11.2, U3.1 (GND), U3.2 (GND); also elsewhere on the board
GP26: C5.1, R11.1, U3.4 (IOUT); also elsewhere on the board

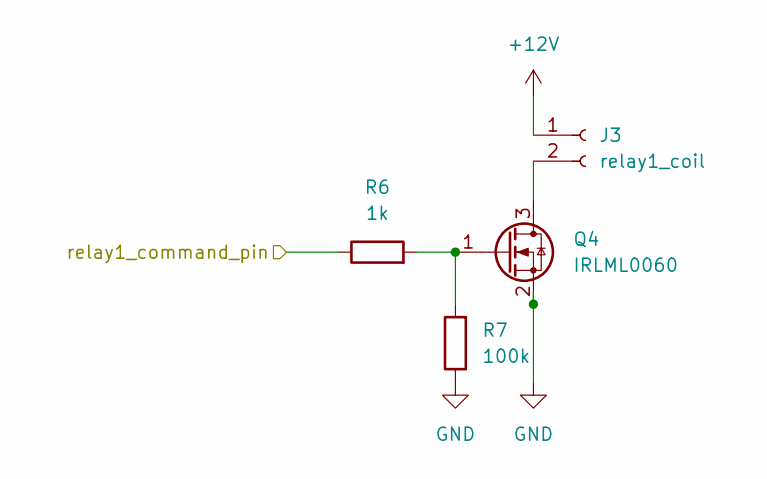
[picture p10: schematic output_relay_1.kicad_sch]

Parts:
J3: relay1_coil; JST_XH_B2B-XH-A_1x02_P2.50mm_Vertical
Q4: IRLML0060; SOT-23
R6: 1k; R_0805_2012Metric_Pad1.20x1.40mm_HandSolder
R7: 100k; R_0805_2012Metric_Pad1.20x1.40mm_HandSolder

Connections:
+12V: J3.1; also elsewhere on the board
GND: Q4.2 (S), R7.1; also elsewhere on the board
GP19: R6.1; also elsewhere on the board
unnamed: J3.2, Q4.3 (D)
unnamed: Q4.1 (G), R6.2, R7.2

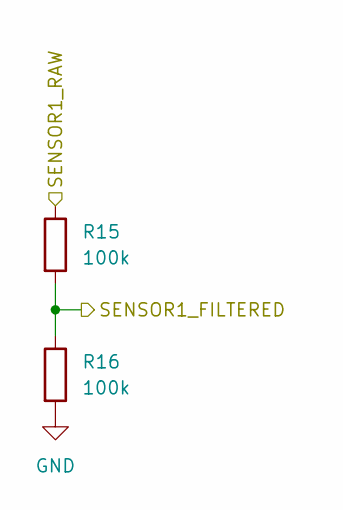
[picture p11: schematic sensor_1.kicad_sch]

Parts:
R15, R16: 100k; R_0805_2012Metric_Pad1.20x1.40mm_HandSolder

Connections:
/ain_1/SENSOR1_RAW: R15.1; also elsewhere on the board
GND: R16.2; also elsewhere on the board
GP28: R15.2, R16.1; also elsewhere on the board

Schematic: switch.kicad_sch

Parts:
SW1: SW_Push; SW_SPST_SKQG_WithoutStem

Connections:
GND: SW1.2; also elsewhere on the board
GP18: SW1.1; also elsewhere on the board

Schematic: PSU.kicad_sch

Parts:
C1: 4u7/100V; C_1206_3216Metric_Pad1.33x1.80mm_HandSolder
C6: 100n/100V; R_0805_2012Metric_Pad1.20x1.40mm_HandSolder
C7: 100n; R_0805_2012Metric_Pad1.20x1.40mm_HandSolder
C8: 22u/16V; C_1206_3216Metric_Pad1.33x1.80mm_HandSolder
C9: 100n/16V; C_1206_3216Metric_Pad1.33x1.80mm_HandSolder
D1: BZX84C15; SOT-23
D2: SMBJ36A; D_SMB
D7: B1100; D_SMA
F1: 1A; Fuse_1206_3216Metric
FB1: 600R/2A; L_1206_3216Metric_Pad1.22x1.90mm_HandSolder
L1: 22uH/1A; L_Bourns_SRN6045TA
Q1: P-MOS 100V; SOT-223-3_TabPin2
R1: 100k; R_0805_2012Metric_Pad1.20x1.40mm_HandSolder
R2: 54k9; R_0805_2012Metric_Pad1.20x1.40mm_HandSolder
R3: 10k; R_0805_2012Metric_Pad1.20x1.40mm_HandSolder
U1: LMR16006XDDCT; SOT-23-6

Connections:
+5V: C8.1, C9.1, L1.2, R2.2; also elsewhere on the board
+12V: D1.1 (K), D2.1 (A1), FB1.1, Q1.2 (S); also elsewhere on the board
GND: C1.2, C6.2, C8.2, C9.2, D2.2 (A2), D7.2 (A), R1.2, R3.2, U1.2 (GND); also elsewhere on the board
unnamed: D1.2 (A), Q1.1 (G), R1.1
unnamed: C7.2, D7.1 (K), L1.1, U1.6 (SW)
unnamed: F1.2, Q1.3 (D)
unnamed: C7.1, U1.1 (CB)
unnamed: R2.1, R3.1, U1.3 (FB)
unnamed: C1.1, C6.1, FB1.2, U1.5 (VIN)
VCC: F1.1; also elsewhere on the board

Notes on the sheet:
Alimentation 5 V / 300 mA - reseau de bord 12 V, apres-contact - LMR16006XDDCT en SOT-23-6 Q1 + R1 + D1 : inversion de polarite - D2 SMBJ36A : veille 36 V, bloquee pendant le load dump a 35 V / 400 ms U1 : 4 a 40 V continu, 65 V transitoire, 0,6 A, 700 kHz (595-805), asynchrone, SOT-23-6 sans plage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

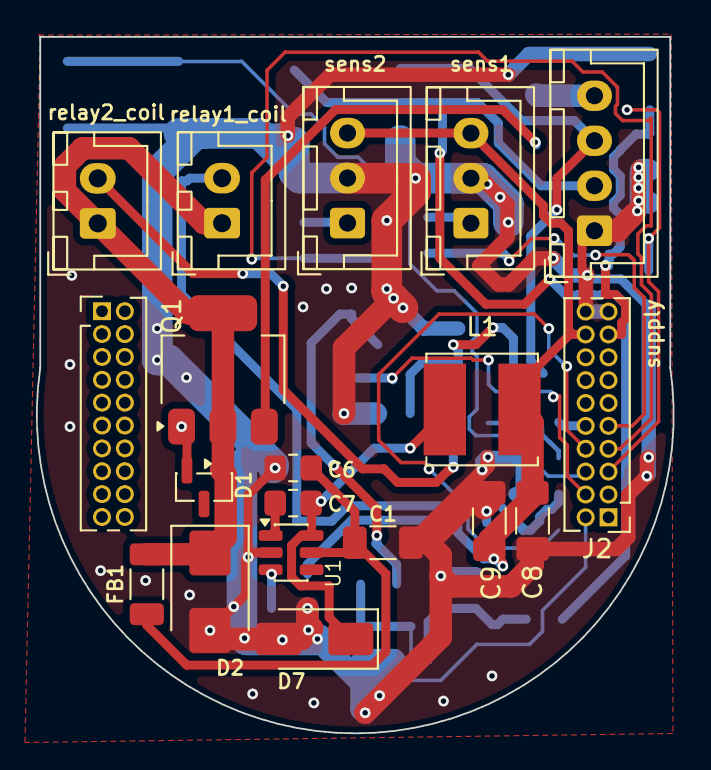
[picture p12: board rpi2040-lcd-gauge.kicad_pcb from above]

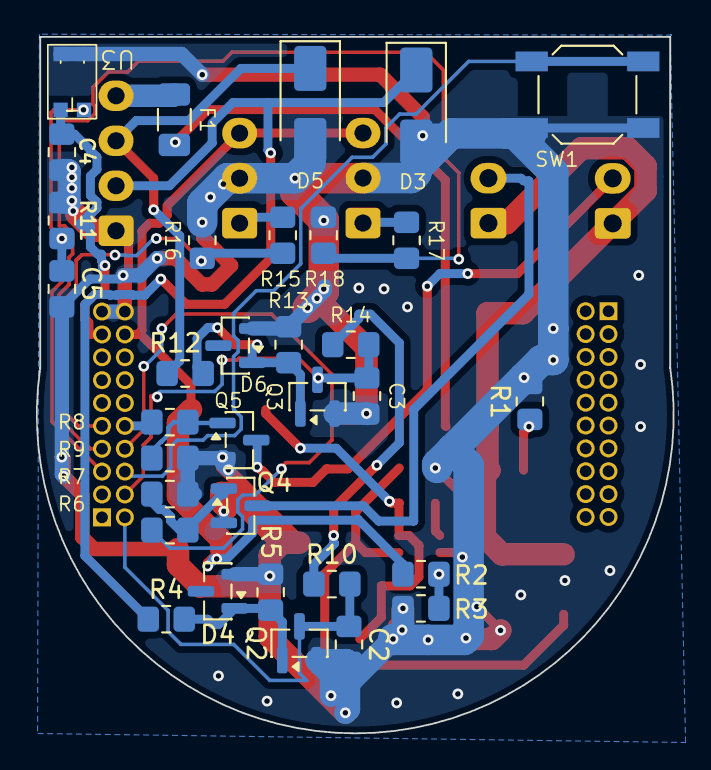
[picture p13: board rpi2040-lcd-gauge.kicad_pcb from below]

Board: 2 copper layers, 35.4 x 38.7 mm, 52 parts (33 on the bottom side), 30 nets.

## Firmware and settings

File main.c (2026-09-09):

/* universal_gauges - entry point.
 *
 * Everything the firmware does is split across five modules:
 *   config.h   the numbers you would tune: sensor spans, scales, backlight
 *   variant.c  the three gauge variants, one of them selected at build time
 *   board.c    the pins, the I2C scan and which module we are running on
 *   sensors.c  the ADC readings and their conversion to engineering units
 *   gauge.c    the frame buffer, the face and the needle
 * What is left here is the bring-up order and the main loop.
 *
 * Built with -DUSE_DEMO=ON, demo.c takes the place of the sensor and sweeps
 * the needle across the face. That is a bench aid, not a normal build.
 */

#include <stdio.h>
#include "pico/stdlib.h"
#include "hardware/rtc.h"

#include "lcd.h"
#include "QMI8658.h"

#include "board.h"
#include "config.h"
#include "gauge.h"
#include "sensors.h"
#include "variant.h"

#ifdef DEMO_MODE
#include "demo.h"
#endif

static void init(void) {
  sleep_ms(100);  /* "Rain-wait": let the other chips come up */
  rtc_init();
  stdio_init_all();

  /* Give the USB host a couple of seconds to enumerate, but do not hang
     waiting for it: the gauge has to work without a computer attached. */
  for (int i = 0; i < 10 && !stdio_usb_connected(); i++) {
    sleep_ms(250);
  }
  sleep_ms(300);

  board_init_gpio();
  sensors_init();

  board_i2c_scan();

  lcd_init();
  gauge_init_display();

  board_init_module_inputs();
  QMI8658_init();

  gauge_init_widgets();
}

int main(void) {
  init();

#ifdef DEMO_MODE
  printf("[%s] demo build: the needle sweeps, the sensor is ignored\n",
         gauge_variant.name);
#endif

  absolute_time_t adc_next = get_absolute_time();

  while (true) {
    if (absolute_time_diff_us(get_absolute_time(), adc_next) <= 0) {
      adc_next = delayed_by_ms(get_absolute_time(), ADC_PERIOD_MS);

      sensors_update();

      printf("[%s] ALS raw=%u %umV %u%%   S1 raw=%u %umV %u%%\n",
             gauge_variant.name,
             als.raw, als.mv, als.percent,
             sensor1.raw, sensor1.mv, sensor1.percent);

#ifndef DEMO_MODE
      gauge_set_light(als.percent);
      gauge_set_value(sensors_value());
#endif
    }

#ifdef DEMO_MODE
    /* Refreshed every frame rather than every ADC period, so the needle
       sweeps smoothly. The inputs above are still read and logged. */
    gauge_set_light(DEMO_LIGHT_PERCENT);
    gauge_set_value(demo_value());
#endif

    gauge_draw();
    sleep_ms(FRAME_PERIOD_MS);
  }

  return 0;
}

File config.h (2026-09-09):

#ifndef CONFIG_H
#define CONFIG_H

/* Every value you would touch to fit a different sensor, a different gauge
   face or a different backlight behaviour lives here. Nothing in this file
   depends on the build variant: variant.c picks which of these spans and
   scales the firmware is built with. */

#include <stdint.h>

/* ---------- ADC sampling ---------- */

#define ADC_SAMPLES   (8)          /* oversampling to smooth out noise */
#define ADC_PERIOD_MS (100)        /* read period in the main loop */
#define ADC_VREF_MV   (3300u)      /* ADC full scale, in mV */
#define ADC_RANGE     (1 << 12)    /* 12-bit ADC -> 0..4095 */
#define ADC_MAX       (ADC_RANGE - 1)

/* ---------- sensor input spans ----------
   In millivolts, measured at the ADC pin. The HAT's input divider, R15 then
   R16 (R17/R18 on the second channel), is stuffed to suit the sender the
   board is built for, so the firmware variant and the board have to match. */

/* Temperature board: R15 6k, R16 10k. The sender is resistive and wired
   between the connector's +5 V and its signal pin, so it becomes the top of
   the divider and the pin reads 5 V * 10k / (R + 16k) - 3125 mV with the
   sender shorted, 0 mV with it open or its wire broken.

   The sender is an NTC: its output is not remotely linear, so it is described
   by the curve below rather than by a span. Measured at the ADC pin, GP28,
   with the sender resistance shown for the record.

   Points must be ordered by rising mV, and MV_MIN / MV_MAX must stay equal to
   the first and last of them - they are what the percentage readout and the
   clamps use. Between two points the reading is interpolated; outside the
   table it is clamped, not extrapolated. */
#define TEMP_SENSOR_MV_MIN     1470
#define TEMP_SENSOR_MV_MAX     2960

#define TEMP_SENSOR_CURVE {   \
  { 1470,  50.f },  /* 17.9 k */ \
  { 1770,  60.f },  /* 12.3 k */ \
  { 2030,  70.f },  /*  8.61 k */ \
  { 2260,  80.f },  /*  6.14 k */ \
  { 2450,  90.f },  /*  4.43 k */ \
  { 2590, 100.f },  /*  3.32 k */ \
  { 2700, 110.f },  /*  2.55 k */ \
  { 2780, 120.f },  /*  1.91 k */ \
  { 2860, 130.f },  /*  1.51 k */ \
  { 2910, 140.f },  /*  1.17 k */ \
  { 2960, 150.f },  /*  0.90 k */ \
}

/* Pressure board: R15 and R16 both 100k. The sender has a voltage output, the
   divider simply halves it, and a 0.5-4.5 V sender lands here. Linear, so no
   curve. */
#define PRESSURE_SENSOR_MV_MIN 250
#define PRESSURE_SENSOR_MV_MAX 2250

#define ALS_MV_MIN             0
#define ALS_MV_MAX             2700

/* ---------- display scales ----------
   Engineering units at the two ends of the gauge face. Change these only if
   the graduations drawn on the face change too. */

#define MIN_TEMP   50.f
#define MAX_TEMP   140.f

#define MIN_PRESS  -0.5f
#define MAX_PRESS  6.5f

/* Reading granularity, in engineering units. The temperature gauges read in
   whole degrees; 0 lets the needle follow the raw conversion. */
#define TEMP_STEP  1.f
#define PRESS_STEP 0.f

/* ---------- backlight ----------
   Driven by the ambient light sensor, between these two limits. */

#define MIN_BRIGHTNESS (uint8_t)1
#define MAX_BRIGHTNESS (uint8_t)100

/* ---------- day and night faces ----------
   The same ambient light reading picks the gauge face. Two thresholds rather
   than one, so a reading sitting right on the edge cannot flip the face back
   and forth; set them equal for a plain single threshold. On top of that the
   new reading has to hold for THEME_HOLD_MS, so a bridge or a row of trees
   does not repaint the screen. */

#define THEME_NIGHT_BELOW (20)    /* % of the ALS span: under it, night face */
#define THEME_DAY_ABOVE   (25)    /* over it, day face; between the two, no
                                     change */
#define THEME_HOLD_MS     (2000)  /* how long the reading has to disagree with
                                     the face on screen before it is swapped */

/* ---------- main loop ---------- */

#define FRAME_PERIOD_MS (10)

/* ---------- demo mode ----------
   Only used by builds configured with -DUSE_DEMO=ON. The needle sweeps the
   face end to end instead of following the sensor. */

#define DEMO_SWEEP_MS       (4000)  /* one end of the face to the other */
#define DEMO_HOLD_MS        (500)   /* pause at each end, to see the stops */
#define DEMO_LIGHT_PERCENT  (100)   /* backlight, so the sweep stays visible
                                       whatever the ambient light */

#endif /* CONFIG_H */

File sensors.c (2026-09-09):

#include "sensors.h"

#include "hardware/adc.h"

#include "board.h"
#include "config.h"
#include "variant.h"

analog_reading_t als     = {0};
analog_reading_t sensor1 = {0};

/* Oversampled raw reading. The channel is selected on every call because
   lcd_module_init() selects BAR_CHANNEL (3) for the battery measurement. */
static uint16_t read_raw(uint8_t channel) {
  adc_select_input(channel);
  uint32_t sum = 0;
  for (int i = 0; i < ADC_SAMPLES; i++) {
    sum += adc_read();
  }
  return (uint16_t)(sum / ADC_SAMPLES);
}

/* raw count -> mV (max 4095 * 3300 = 13.5e6, fits in uint32_t). */
static uint16_t raw_to_mv(uint16_t raw) {
  return (uint16_t)(((uint32_t)raw * ADC_VREF_MV) / ADC_MAX);
}

/* mV -> 0..100 % over [mv_min, mv_max], clamped. */
static uint8_t mv_to_percent(uint16_t mv, uint16_t mv_min, uint16_t mv_max) {
  if (mv_max <= mv_min) { return 0; }
  if (mv <= mv_min)     { return 0; }
  if (mv >= mv_max)     { return 100; }
  return (uint8_t)(((uint32_t)(mv - mv_min) * 100u) / (uint32_t)(mv_max - mv_min));
}

/* mV -> engineering units, linear over [mv_min, mv_max] -> [out_min, out_max].
   A reading outside the span is clamped, not extrapolated. */
static float mv_to_range(uint16_t mv, uint16_t mv_min, uint16_t mv_max,
                         float out_min, float out_max) {
  if (mv_max <= mv_min) { return out_min; }
  if (mv <= mv_min)     { return out_min; }
  if (mv >= mv_max)     { return out_max; }
  float factor = (float)(mv - mv_min) / (float)(mv_max - mv_min);
  return out_min + (out_max - out_min) * factor;
}

/* mV -> engineering units through a calibration curve, interpolated between
   the two points that frame the reading. Outside the table the reading is
   clamped to its ends. The table has to be ordered by rising mV. */
static float mv_through_curve(uint16_t mv, const curve_point_t* c, uint8_t n) {
  if (n == 0)          { return 0.f; }
  if (mv <= c[0].mv)   { return c[0].value; }
  if (mv >= c[n-1].mv) { return c[n-1].value; }

  uint8_t i = 1;
  while (i < (uint8_t)(n - 1) && mv > c[i].mv) { i++; }

  const uint16_t lo_mv = c[i-1].mv;
  const uint16_t hi_mv = c[i].mv;
  if (hi_mv <= lo_mv) { return c[i].value; }

  const float factor = (float)(mv - lo_mv) / (float)(hi_mv - lo_mv);
  return c[i-1].value + (c[i].value - c[i-1].value) * factor;
}

/* Reads one channel and fills the three fields in one go. */
static void read_input(analog_reading_t* r, uint8_t channel,
                       uint16_t mv_min, uint16_t mv_max) {
  r->raw     = read_raw(channel);
  r->mv      = raw_to_mv(r->raw);
  r->percent = mv_to_percent(r->mv, mv_min, mv_max);
}

void sensors_init(void) {
  adc_init();
  adc_gpio_init(ALS_OUT);
  adc_gpio_init(SENSOR1_FILTERED);
  adc_gpio_init(SENSOR2_FILTERED);
}

void sensors_update(void) {
  read_input(&als, ALS_ADC_CHANNEL, ALS_MV_MIN, ALS_MV_MAX);
  read_input(&sensor1, SENSOR1_ADC_CHANNEL,
             gauge_variant.sensor_mv_min, gauge_variant.sensor_mv_max);
}

float sensors_value(void) {
  if (gauge_variant.curve != NULL) {
    return mv_through_curve(sensor1.mv,
                            gauge_variant.curve, gauge_variant.curve_len);
  }
  return mv_to_range(sensor1.mv,
                     gauge_variant.sensor_mv_min, gauge_variant.sensor_mv_max,
                     gauge_variant.value_min, gauge_variant.value_max);
}

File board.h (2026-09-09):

#ifndef BOARD_H
#define BOARD_H

#include <stdint.h>

/* ---------- signals added by the HAT ----------
   Same table as the pinout section of README.md. */

#define SHIFTED_DIGITAL_IN1 (16)  /* input                  */
#define SHIFTED_DIGITAL_IN2 (17)  /* input                  */
#define BUTTON_INPUT        (18)  /* input, pull-up         */
#define RELAY1_COMMAND_PIN  (19)  /* output                 */
#define RELAY2_COMMAND_PIN  (20)  /* output                 */
#define ALS_OUT             (26)  /* analog input, ADC0     */
#define SENSOR2_FILTERED    (27)  /* analog input, ADC1     */
#define SENSOR1_FILTERED    (28)  /* analog input, ADC2     */

/* ---------- ADC channels ----------
   The RP2040 channel is not the GPIO number:
   GP26=ADC0, GP27=ADC1, GP28=ADC2, GP29=ADC3 (the module's battery sense). */

#define ALS_ADC_CHANNEL     (0)
#define SENSOR2_ADC_CHANNEL (1)
#define SENSOR1_ADC_CHANNEL (2)

/* ---------- pins of the module itself ----------
   Display, I2C, IMU, backlight and battery are in lib/lcd/lcd.h.

   This firmware targets the RP2040-LCD-1.28 only. The touch variant, whose
   button sits on GP16 and would collide with SHIFTED_DIGITAL_IN1, is not
   supported. */

#define QMIINT1       (23)  /* IMU interrupt                       */
#define MODULE_BUTTON (22)  /* button on the module, distinct from
                               BUTTON_INPUT which is SW1 on the HAT */

/* I2C bus, relays, button and digital inputs. */
void board_init_gpio(void);

/* Walks the I2C bus and prints it. A boot diagnostic: the IMU should answer. */
void board_i2c_scan(void);

/* IMU interrupt and module button, both edge triggered. */
void board_init_module_inputs(void);

#endif /* BOARD_H */

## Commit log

2026-09-09 rename trans -> gearbox, versioned firmware images
2026-09-09 added schematic and pcb
    [PSU.kicad_sch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]
2026-09-09 updated oil_t bg
    [PSU.kicad_sch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]
2026-09-09 now with a working day-night automatic toggle, along with an accurante temperature sensor calibration
